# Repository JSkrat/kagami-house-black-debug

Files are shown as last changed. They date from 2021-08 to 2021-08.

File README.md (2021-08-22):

# kagami-house-black-debug
Debug board with uart and lcd, also it is a modem

## Project structure

- hw contains schematic and pcb
- fw contains the firmware
- fw/usb2nrf_tests contains unadapted unit tests (TODO: adapt to submoduled avr core)
- serial-debugger is gui qt app to control the board via usb (uart)

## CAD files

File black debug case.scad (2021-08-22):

$fn=180;
tolerance = 0.1;
wall = 1.2;
pcb_margin = 0.5;
pcb_x = 69.5;
pcb_y = 72.1;
pcb_z = 1.6;
strut_bolt_h = 6;
bottom_strut_h = 6;
// the height of the body part of the strut
top_strut_h = 10;
bolt_d = 3.2;
// bolt head
bolt_head_h = 2.3;
bolt_head_d = 5.5;
// from the tip of the strut at bottom to the pcb top surface
pcb_h = strut_bolt_h+bottom_strut_h+pcb_z;
// the height of the upper part, pcb top surface to case top surface
upper_case_h = 14 + wall;//top_strut_h + wall + bolt_head_h;
//buttons = [[5.5, 9.7], [31.9, 9.7], [62.6, 18]];
buttons = [[62.6, 18]];
button_d = 6.5;
button_h = 4.5;
button_dz = 1.35;
//leds = [[63.36, 28.04], [63.36, 26.04], [21.84, 48.88], [24.38, 48.88], [26.29, 48.88]];
leds = [[63.36, 28.04], [63.36, 26.04], [21.84, 46.3], [24.38, 46.3], [26.29, 46.3]];
hole_support_thickness = 0.3;
nrf_extend = 6;

module usb() {
    color("#333")
    translate([16, 0, 0])
    cube([28, 16, 1.8]);
    color("silver")
    translate([0, 2, 0.5])
    cube([16, 12, 4.5]);
}

module nrf() {
    color("#333")
    cube([15.3, 29.1, 1.2]);
}

module lcd() {
    color("#DDD")
    cube([36, 31, 1.8]);
    
    color("#AAA")
    translate([1.2, 1.2, 1])
    cube([33.5, 25.5, 1.7]);
}

module pcb() {
    import("pcb.stl");
    translate([-14, 50, 8.5])
    mirror([0, 0, 1])
    usb();
    translate([53.2, 36.3, 7])
    nrf();
    translate([0, 13, pcb_z+2])
    lcd();
    // struts
    for (x = [3.5, 66], y = [3.53, 68.534]) {
        translate([x, y, -12])
        bottom_strut();
        translate([x, y, pcb_z])
        top_strut();
    }
}

module bottom_strut() {
    // nut
    nut_h = 2.5 + 0.5;
    color("#AAA")
    translate([0, 0, -tolerance])
    cylinder(d=6.3+tolerance*2, h = nut_h+tolerance, $fn=6);
    // bolt
    translate([0, 0, nut_h + hole_support_thickness])
    color("#222")
    cylinder(d=bolt_d+tolerance*2, h = bottom_strut_h+strut_bolt_h - nut_h);
    // body
    color("#222")
    translate([0, 0, strut_bolt_h])
    cylinder(d = 6.3 + tolerance*2, h = bottom_strut_h, $fn=6);
}

module top_strut() {
    // bolt
    color("#222")
    translate([0, 0, -6])
    cylinder(d = bolt_d+tolerance*2, h = top_strut_h+strut_bolt_h + wall - hole_support_thickness);
    // body
    color("#222")
    cylinder(d = 6.3 + tolerance*2, h = top_strut_h);
    // bolt head
    color("#222")
    translate([0, 0, top_strut_h + wall])
    cylinder(d = bolt_head_d + tolerance*2, h = bolt_head_h + tolerance + 100);
}

module button() {
    button_exposed = 1;
    intersection() {
        union() {
            cylinder(d = button_d - tolerance*4, h = upper_case_h - button_h);
            cube([button_d + wall*2 - tolerance*4, 2 - tolerance*4, (wall + button_dz*2 - tolerance*4)*2], center=true);
            translate([0, 0, upper_case_h - button_h])
            resize([button_d - tolerance*4, button_d - tolerance*4, button_exposed*2])
            sphere(d = button_d - tolerance*2);
        }
        cylinder(d = button_d + wall*2, h = upper_case_h - button_h + button_exposed);
    }
}

module screw() {
    cylinder(d=4, h=15);
    cylinder(d1 = 8, d2 = 4, h = 2.4);
}

module mount() {
    difference() {
        hull() {
            cylinder(d = 15, h = 3);
            translate([0, 15, 0])
            cylinder(d = 15, h = 3);
        }
        translate([0, 15, 3 + tolerance])
        rotate(180, [1, 0, 0])
        screw();
    }
}

module lower_half() {
    color("#666")
    difference() {
        union() {
            difference() {
                union() {
                    // body
                    cube([pcb_x + pcb_margin*2 + wall*2, pcb_y + pcb_margin*2 + wall*2 + nrf_extend, pcb_h - wall/2]);
                    // edge
                    translate([wall/2+tolerance/2, wall/2+tolerance/2, 0])
                    cube([pcb_x + pcb_margin*2 + wall*2-wall-tolerance, pcb_y + pcb_margin*2 + wall*2  + nrf_extend -wall-tolerance, pcb_h]);
                    // mounts
                    translate([(pcb_x + pcb_margin*2 + wall*2)/2, pcb_y + pcb_margin*2 + wall*2 + nrf_extend - 9, 0])
                    mount();
                    translate([(pcb_x + pcb_margin*2 + wall*2)/2, 9, 0])
                    rotate(180, [0, 0, 1])
                    mount();
                }
                
                translate([wall, wall, wall])
                cube([pcb_x + pcb_margin*2, pcb_y + pcb_margin*2 + nrf_extend, pcb_h]);
            }
            for (x = [3.5, 66], y = [3.53, 68.534]) {
                translate([x+wall+pcb_margin, y+wall+pcb_margin, 0]) {
                    cylinder(d = 9, h = 4);
                    translate([0, 0, 4])
                    cylinder(d1=9, d2=6, h=2);
                }
            }
        }
        translate([wall+pcb_margin, wall+pcb_margin, 12])
        pcb();
    }
}

module upper_half_normal() {
    pcb_offset = wall+pcb_margin;
    color("#668")
    difference() {
        union() {
            difference() {
                // body
                translate([0, 0, -wall/2])
                cube([pcb_x + pcb_margin*2 + wall*2, pcb_y + pcb_margin*2 + wall*2 + nrf_extend, upper_case_h + wall/2]);
                // main cavity
                translate([wall, wall, -tolerance])
                cube([pcb_x + pcb_margin*2, pcb_y + pcb_margin*2 + nrf_extend, upper_case_h - wall + tolerance]);
                // little edge
                translate([wall/2-tolerance/2, wall/2-tolerance/2, -wall/2 - tolerance])
                cube([pcb_x + pcb_margin*2 + wall*2 - wall+tolerance, pcb_y + pcb_margin*2 + wall*2 + nrf_extend - wall + tolerance, wall/2 + tolerance]);
            }
            // for bolts
            for (x = [3.5, 66], y = [3.53, 68.534]) {
                translate([x+wall+pcb_margin, y+wall+pcb_margin, top_strut_h]) {
                    cylinder(d = 9, h = upper_case_h - top_strut_h);
                }
            }
            // lcb support
            lcd_top = 2 + 2.7 + tolerance;
            translate([0+pcb_margin+wall, 13+pcb_margin+wall, lcd_top])
            *cube([33.5+1.2*2, 25.5+1.2*2, upper_case_h-lcd_top]);
            // buttons casings
            for (c = buttons) {
                translate([pcb_offset + c[0], pcb_offset + c[1], button_h + tolerance])
                cylinder(d = button_d + wall*2, h = upper_case_h - button_h - tolerance);
            }
            // for lights
            led_h = 1;
            for (c = leds) {
                translate([pcb_offset + c[0], pcb_offset + c[1], led_h])
                cylinder(d = 1.75 + wall, h = upper_case_h - led_h);
            }

        }
        translate([wall+pcb_margin, wall+pcb_margin, -pcb_z])
        pcb();
        // cuts
        cut_h = upper_case_h + tolerance*2;
        // for usb
        translate([-tolerance, 46, -wall])
        cube([tolerance*2 + wall, 21, 8 + wall]);
        // for lcd
        lcd_padding = 1.5/2;
        translate([0+1.2+pcb_offset+lcd_padding, 13+1.2+pcb_offset + lcd_padding, 0])
        *cube([33.5 - lcd_padding*2, 25.5 - lcd_padding*2, cut_h]);
        // for buttons
        for (c = buttons) {
            translate([pcb_offset + c[0], pcb_offset + c[1], button_h - tolerance]) {
                // holes without tolerance to drill the layers for smoothness
                cylinder(d = button_d, h = upper_case_h - button_h + tolerance*2);
                cube([button_d + wall*2 + tolerance*2, 2 + tolerance*2, (wall + button_dz*2 + tolerance*2)*2], center=true);
            }
        }
        // for rotator
        translate([pcb_offset + 49.94, pcb_offset + 9.084, 0])
        *cylinder(d = 7 + tolerance*2, h = cut_h);
        // for lights
        for (c = leds) {
            translate([pcb_offset + c[0], pcb_offset + c[1], -tolerance])
            cylinder(d = 1.75 + tolerance*2, h = cut_h);
        }
        // cut in lights housings for usb
        translate([pcb_offset + 19, pcb_offset + leds[2][1] -wall*2, 0])
        cube([10, 5, upper_case_h - wall]);
        // cut for crystal on nrf
        translate([pcb_offset + 63, pcb_offset + 41, upper_case_h - wall - tolerance])
        *cube([4.5, 15, wall/2]);
        // text
        translate([12, 68, upper_case_h - 0.4])
        rotate(-90, [0, 0, 1])
        linear_extrude(wall)
        text("Kagami house black", 4);
        translate([25, 50, upper_case_h - 0.4])
        linear_extrude(wall)
        text("R T", 2);
        // hole for the antenna
        translate([58, wall+pcb_offset + 74.6, 10.3])
        rotate(90, [-1, 0, 0])
        cylinder(d = 6.3 + tolerance*2, h = wall*4);
    }
}

module assembly() {
    lower_half();
    translate([0, 0, pcb_h]) 
    upper_half_normal();
    translate([wall+pcb_margin, wall+pcb_margin, 12])
    *pcb();
}


// bolt cut inspection
*intersection() {
    assembly();
    translate([-tolerance, -tolerance, -tolerance])
    cube([pcb_x + wall*2+pcb_margin*2 + tolerance*2, 3.53+wall+pcb_margin + tolerance, pcb_h + upper_case_h + tolerance*2]);
}

*assembly();
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

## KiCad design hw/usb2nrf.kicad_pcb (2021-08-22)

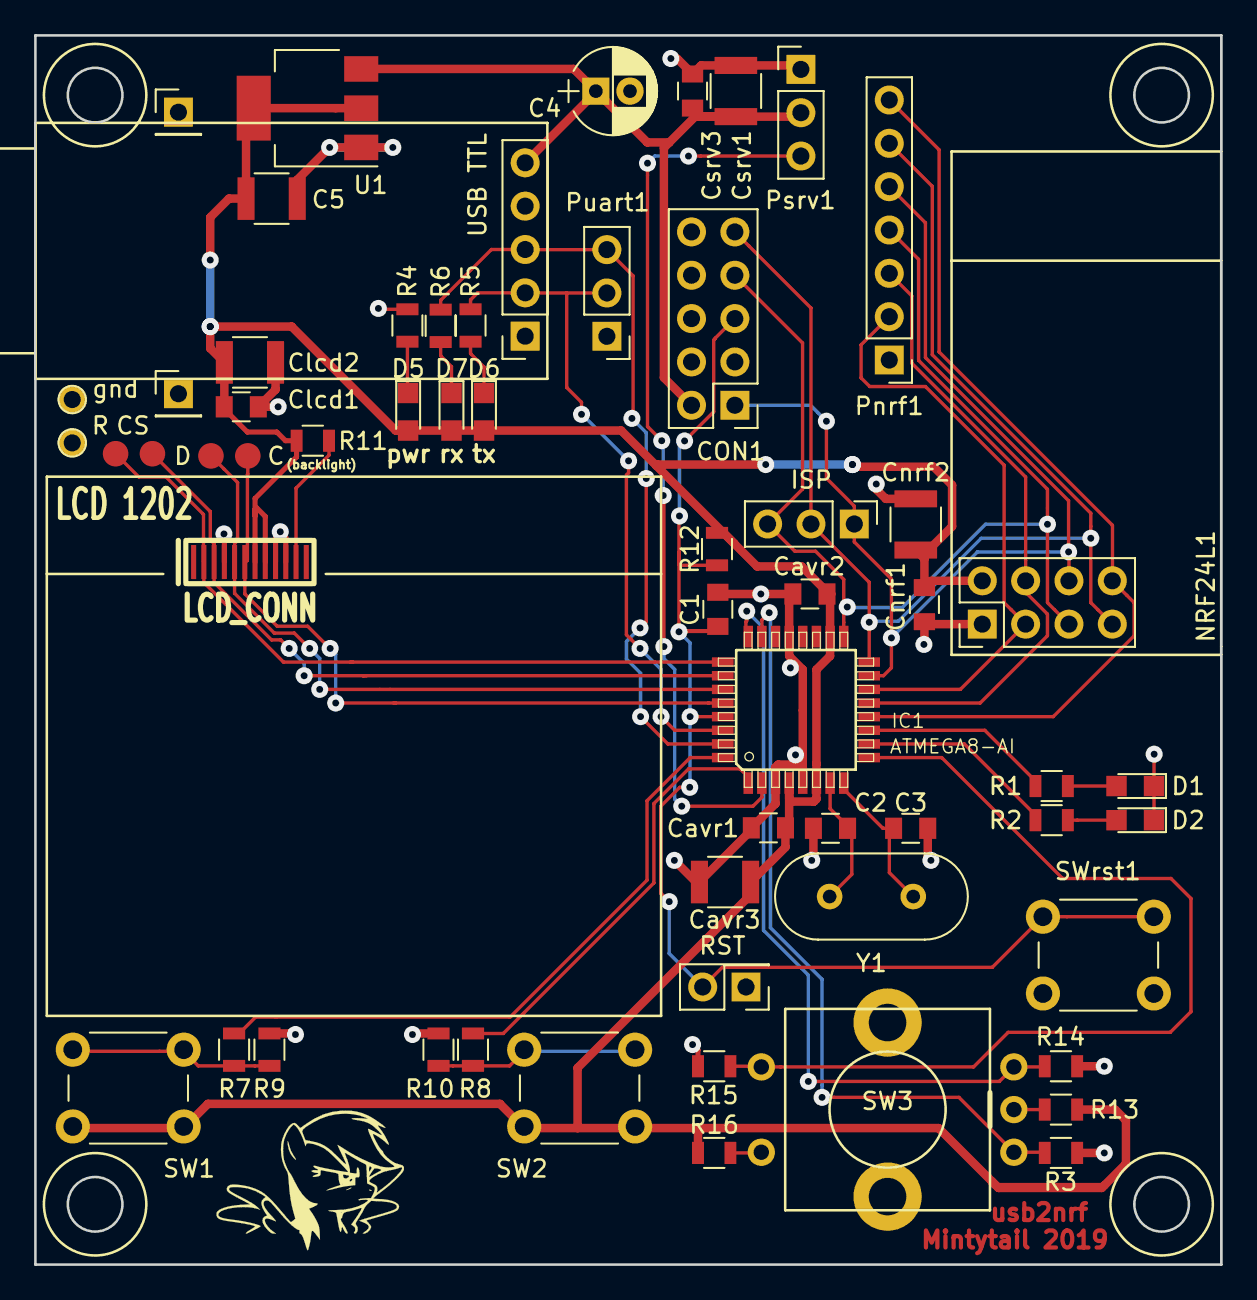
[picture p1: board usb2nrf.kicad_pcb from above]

Board: 2 copper layers, 69.5 x 72.0 mm, 58 parts (0 on the bottom side), 36 nets.

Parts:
C: Measurement_Point_Round-SMD-Pad_Small
C1: 100n; C_0805
C2, C3: 22p; C_0805
C4: 10u; CP_Radial_D5.0mm_P2.00mm
C5: 10u; C_1210
CON1: AVR-JTAG-10; Pin_Header_Straight_2x05_Pitch2.54mm
CS: Measurement_Point_Round-SMD-Pad_Small
Cavr1, Cavr2: 100n; C_0805
Cavr3: 10u; C_1210
Clcd1: 100n; C_0805
Clcd2: 10u; C_1210
Cnrf1: 100n; C_0805
Cnrf2: 10u; C_1210
Csrv1: 10u; C_1210
Csrv3: 100n; C_0805
D: Measurement_Point_Round-SMD-Pad_Small
D1, D2, D5, D6, D7: LED; LED_0805
IC1: ATMEGA8-AI; atmega8-TQFP32-08
ISP: CONN_01X03; Pin_Header_Straight_1x03_Pitch2.54mm
LCD 1202: LCD_CONN; SIL-12
NRF24L1: NRF24L01; Pin_Header_Straight_2x04_Pitch2.54mm
P3, P6: CONN_01X01; Pin_Header_Straight_1x01_Pitch2.54mm
Pnrf1: nrf_test; Pin_Header_Straight_1x07_Pitch2.54mm
Psrv1: CONN_srv; Pin_Header_Straight_1x03_Pitch2.54mm
Puart1: uart_test; Pin_Header_Straight_1x03_Pitch2.54mm
R: Measurement_Point_Round-SMD-Pad_Small
R1, R2, R4, R5, R6, R11: R; R_0805
R3, R9, R10, R14, R15: 10k; R_0805
R7, R8: 150; R_0805
R12: 47k; R_0805
R13, R16: 511; R_0805
RST: CONN_01X02; Pin_Header_Straight_2x01_Pitch2.54mm
SW1, SW2: SW_Push; SW_PUSH_6mm_h4.3mm
SW3: Rotary_Encoder_Switch; encoder
SWrst1: SW_Push; SW_PUSH_6mm_h4.3mm
U1: AMS1117-3.3; SOT-223-3_TabPin2
USB TTL: USBTTL; Pin_Header_Straight_1x05_Pitch2.54mm
Y1: 16M; Crystal_HC18-U_Vertical
gnd: PINTST

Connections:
/3v3: C5.1, Cavr1.1, Cavr2.1, Cavr3.1, Clcd1.2, Clcd2.1, Cnrf1.2, Cnrf2.1, D5.2, D6.2, D7.2, IC1.4, IC1.6, IC1.18, LCD 1202.7, LCD 1202.8, NRF24L1.8, R11.2, R12.1, R13.1, R16.1, SW1.2, SW2.2, U1.2
/5v: C4.1, CON1.2, Csrv1.1, Csrv3.1, Psrv1.2, U1.3, USB TTL.5
/ce: IC1.14, NRF24L1.2, Pnrf1.2
/csn: IC1.13, NRF24L1.7, Pnrf1.3
/enc_btn: IC1.9, R15.1, SW3.S2
/irq: IC1.12, NRF24L1.5, Pnrf1.7
/lcd_backlight: LCD 1202.11, R11.1
/lcd_clk: C.1, IC1.28, LCD 1202.6
/lcd_cs: CS.1, IC1.26, LCD 1202.3
/lcd_rst: IC1.25, LCD 1202.2, R.1
/lcd_sda: D.1, IC1.27, LCD 1202.5
/miso: CON1.9, IC1.16, ISP.2, NRF24L1.4, Pnrf1.6
/mosi: CON1.1, IC1.15, ISP.1, NRF24L1.6, Pnrf1.5
/reset: C1.1, CON1.5, IC1.29, R12.2, RST.2, SWrst1.1
/rx_usb: IC1.31, Puart1.3, R6.1, USB TTL.3
/sck: CON1.7, IC1.17, ISP.3, NRF24L1.3, Pnrf1.4
/tx_usb: IC1.30, Puart1.2, R5.1, USB TTL.2
/xtal1: C2.1, IC1.7, Y1.1
/xtal2: C3.1, IC1.8, Y1.2
GNDPWR: C1.2, C2.2, C3.2, C4.2, C5.2, CON1.4, CON1.6, CON1.8, CON1.10, Cavr1.2, Cavr2.2, Cavr3.2, Clcd1.1, Clcd2.2, Cnrf1.1, Cnrf2.2, Csrv1.2, Csrv3.2, D1.1, D2.1, IC1.3, IC1.5, IC1.21, LCD 1202.4, LCD 1202.9, LCD 1202.10, NRF24L1.1, P3.1, P6.1, Pnrf1.1, Psrv1.1, Puart1.1, R3.2, R4.2, R9.2, R10.1, R14.2, R15.2, RST.1, SW3.6, SWrst1.2, U1.1, USB TTL.4, gnd.1
unnamed: D1.2, R1.2
unnamed: D2.2, R2.2
unnamed: D5.1, R4.1
unnamed: D6.1, R5.2
unnamed: D7.1, R6.2
unnamed: IC1.1, R8.2
unnamed: IC1.2, Psrv1.3
unnamed: IC1.10, R2.1
unnamed: IC1.11, R1.1
unnamed: IC1.23, R3.1, SW3.A
unnamed: IC1.24, R14.1, SW3.B
unnamed: IC1.32, R7.2
unnamed: R7.1, R9.1, SW1.1
unnamed: R8.1, R10.2, SW2.1
unnamed: R13.2, SW3.C
unnamed: R16.2, SW3.S1

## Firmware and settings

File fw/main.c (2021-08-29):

/*
 * black-debug.c
 *
 * Created: 21.08.2021 15:47:05
 * Author : Mintytail
 */ 

#include <avr/io.h>
#include <avr/interrupt.h>
#include <avr/sleep.h>
#include "KagamiCore/UART parser.h"
#include "KagamiCore/RF model.h"
#include "ui.h"
#include "RF custom functions.h"

ISR(BADISR_vect, ISR_NAKED) {
	// nothing here
}


int main(void)
{
    /* hardware initialization */
#if BT_MASTER == BUILD_TYPE
	u_init();
#endif
	ui_init();
	rf_init();
	RFCustomFunctionsInit();
	set_sleep_mode(SLEEP_MODE_IDLE);
	sei();
    while (1) {
		ui_e_main_cycle();
		sleep_mode();
    }
}

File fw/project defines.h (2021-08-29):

#define F_CPU 16000000

// RF mode
#define BUILD_TYPE BT_MASTER

// transciever
#define portTransiever PORTB
#define PORT_IN_TRANSIEVER PINB
#define poTransiever_IRQ PORTB0
#define RF_TIMER 2

/*** USART ***/
#define BAUDRATE 200000

/*** LCD ***/
#define CEILING(x,y) (((x) + (y) - 1) / (y))
//#define USE_LCD
#define portLCD PORTC
#define poLCD_CS PORTC3
#define poLCD_DATA PORTC4
#define poLCD_CLK PORTC5
#define poLCD_RST PORTC2

#define LCD_WIDTH	96
#define LCD_HEIGHT	68
#define LCD_PAGES	9
// высота букавы — 8 пикселей
#define FONT_HEIGHT 8
#define FONT_WIDTH	6
#define LCD_ROWS	CEILING(LCD_HEIGHT, FONT_HEIGHT)
#define LCD_COLUMNS CEILING(LCD_WIDTH, FONT_WIDTH)

/*** LEDs ***/
#define portLEDS PORTD
#define poLED_D1 PORTD7
#define poLED_D2 PORTD6

/*** buttons ***/
#define portButtons PORTD
#define piSW1 PIND2
#define piSW2 PIND3

#define portServo PORTD
#define poServo PORTD4

/** RF packet **/
/*** encryption ***/
#define RF_ENC_TOTAL 1

// show error codes
#ifndef __ASSEMBLY__
void ui_error(unsigned char code);
#undef RF_ERROR
#define RF_ERROR(code) ui_error(code)
#endif
